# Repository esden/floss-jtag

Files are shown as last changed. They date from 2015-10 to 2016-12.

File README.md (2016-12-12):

Free Libre Open-Source/-Hardware JTAG/UART Adapter based on the FT2232H chip.

The hardware is licensed under Creative Commons Share Alike By Attribution 3.0 (CC-BY-SA 3.0)

Copyright 2009-2010 Piotr Esden-Tempski

# UART connector adapter side:

| Pin No. | Name  |
|---|---|
| 1 | +3.3V |
| 2 |  TXD  |
| 3 |  RXD  |
| 4 |  GND  |

The numbering of the connector is from left to right when looking from the edge
of the board at the pins of the header.

# Hardware design file notes:

All designs up until version 1.0 of Floss-JTAG were
designed in Cadsoft EAGLE. To view the files you will need to install EAGLE.
Most of the designs are 4-layer; this means that you will need a paid version
of the software to edit the inner layers of the board.

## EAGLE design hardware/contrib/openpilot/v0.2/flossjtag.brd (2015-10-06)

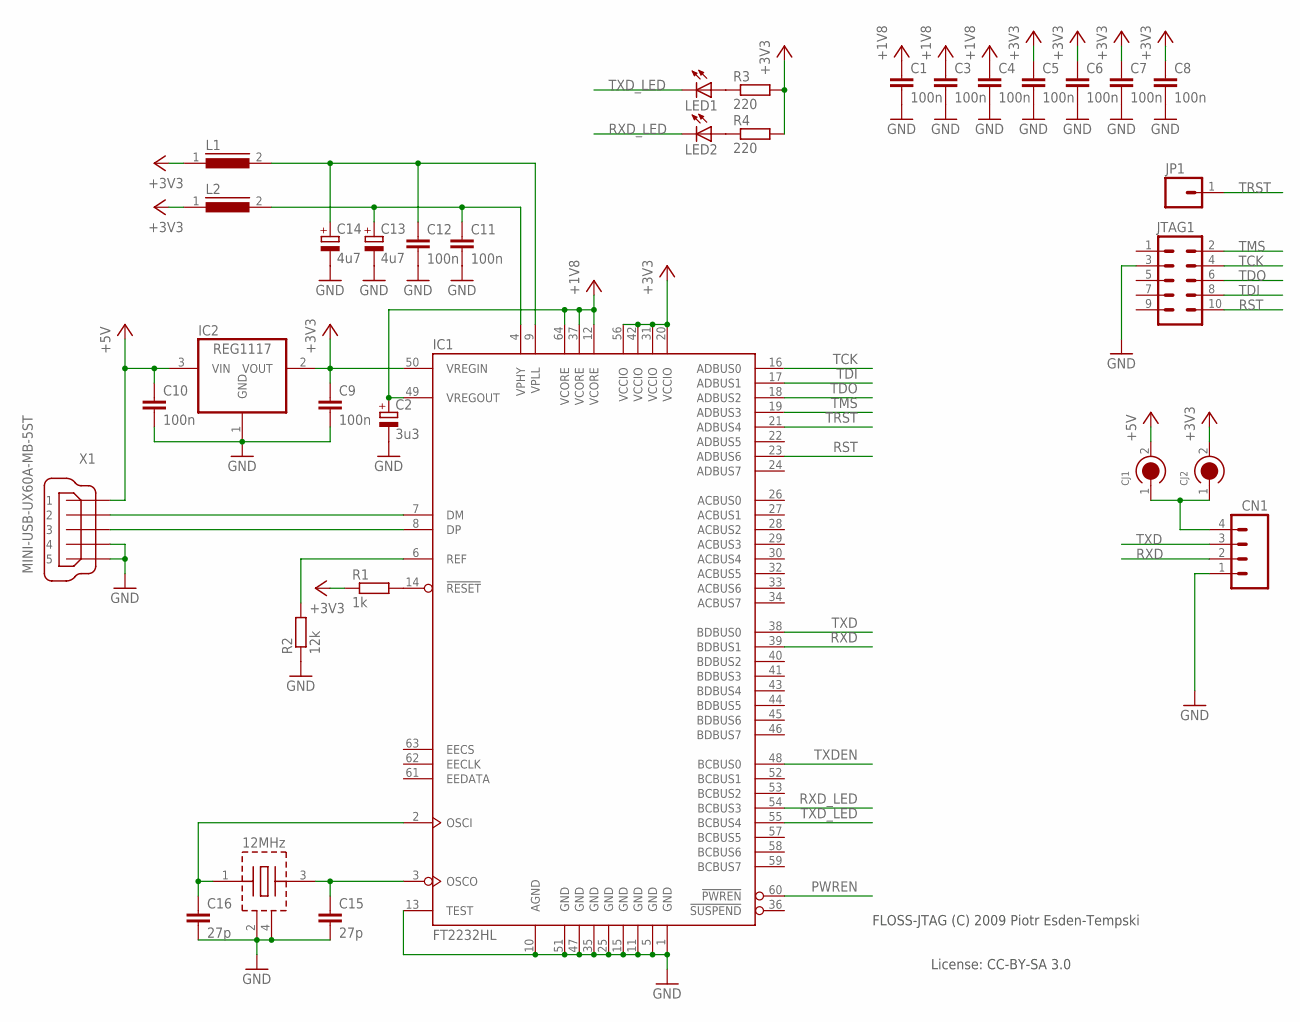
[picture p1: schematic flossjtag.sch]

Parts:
C1, C3, C4, C5, C6, C7, C8, C9, C10, C11, C12: 100n; C0603
C2: 3u3; A/3216-18R
C13, C14: 4u7; A/3216-18R
C15, C16: 27p; C0603
CJ1, CJ2: CIRC_JMP
CN1: SM04B-SRSS-TB
IC1: FT2232HL; LQFP64
IC2: REG1117; SOT223
JP1: PAD-0.06
JTAG1: JTAG-EDGE
L1, L2: I0603; R0603
LED1, LED2: LEDCHIP-LED0603; CHIP-LED0603
R1: 1k; R0603
R2: 12k; R0603
R3, R4: 220; R0603
X1: MINI-USB-UX60A-MB-5ST; UX60A-MB-5ST
X3: 12MHz; NX3225SA

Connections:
+3V3: C5.1, C6.1, C7.1, C8.1, C9.1, CJ2.2, IC1.20 (VCCIO), IC1.31 (VCCIO), IC1.42 (VCCIO), IC1.50 (VREGIN), IC1.56 (VCCIO), IC2.2 (VOUT), L1.1, L2.1, R1.1, R3.2, R4.2
+5V: C10.1, CJ1.2, IC2.3 (VIN), X1.1
GND: C1.2, C2.-, C3.2, C4.2, C5.2, C6.2, C7.2, C8.2, C9.2, C10.2, C11.2, C12.2, C13.-, C14.-, C15.2, C16.2, CN1.1, IC1.1 (GND), IC1.5 (GND), IC1.10 (AGND), IC1.11 (GND), IC1.13 (TEST), IC1.15 (GND), IC1.25 (GND), IC1.35 (GND), IC1.47 (GND), IC1.51 (GND), IC2.1 (GND), JTAG1.3, R2.1, X1.4, X1.5, X3.2 (GND), X3.4 (GND)
unnamed: IC1.14 (!RESET), R1.2
unnamed: IC1.6 (REF), R2.2
unnamed: IC1.7 (DM), X1.2
unnamed: IC1.8 (DP), X1.3
unnamed: CJ1.1, CJ2.1, CN1.4
unnamed: C16.1, IC1.2 (OSCI), X3.1 (XTAL)
unnamed: C12.1, C14.+, IC1.9 (VPLL), L1.2
unnamed: C11.1, C13.+, IC1.4 (VPHY), L2.2
unnamed: C15.1, IC1.3 (OSCO), X3.3 (XTAL)
unnamed: LED1.A, R3.1
unnamed: LED2.A, R4.1
PWREN: IC1.60 (!PWREN)
RST: IC1.23 (ADBUS6), JTAG1.10
RXD: CN1.2, IC1.39 (BDBUS1)
RXD_LED: IC1.54 (BCBUS3), LED2.C
TCK: IC1.16 (ADBUS0), JTAG1.4
TDI: IC1.17 (ADBUS1), JTAG1.8
TDO: IC1.18 (ADBUS2), JTAG1.6
TMS: IC1.19 (ADBUS3), JTAG1.2
TRST: IC1.21 (ADBUS4), JP1.1
TXD: CN1.3, IC1.38 (BDBUS0)
TXDEN: IC1.48 (BCBUS0)
TXD_LED: IC1.55 (BCBUS4), LED1.C
VCC: C1.1, C2.+, C3.1, C4.1, IC1.12 (VCORE), IC1.37 (VCORE), IC1.49 (VREGOUT), IC1.64 (VCORE)

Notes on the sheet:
FLOSS-JTAG (C) 2009 Piotr Esden-Tempski
License: CC-BY-SA 3.0

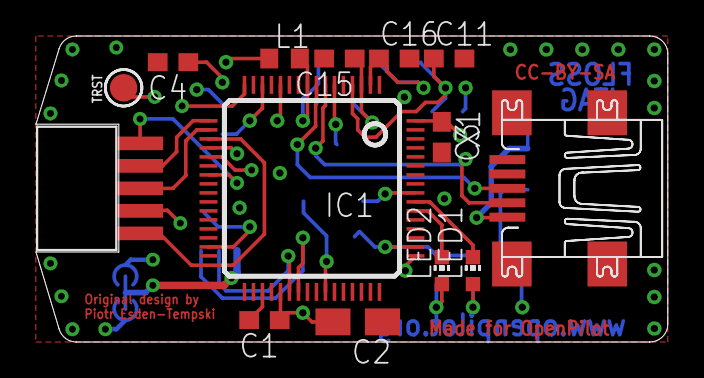
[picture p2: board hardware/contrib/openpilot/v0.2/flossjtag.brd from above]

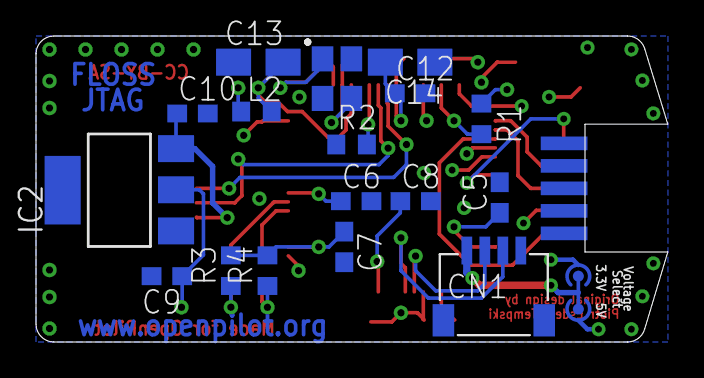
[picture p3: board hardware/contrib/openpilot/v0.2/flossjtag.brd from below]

Board: 4 copper layers, 35.1 x 17.0 mm, 33 parts (19 on the bottom side), 25 nets.

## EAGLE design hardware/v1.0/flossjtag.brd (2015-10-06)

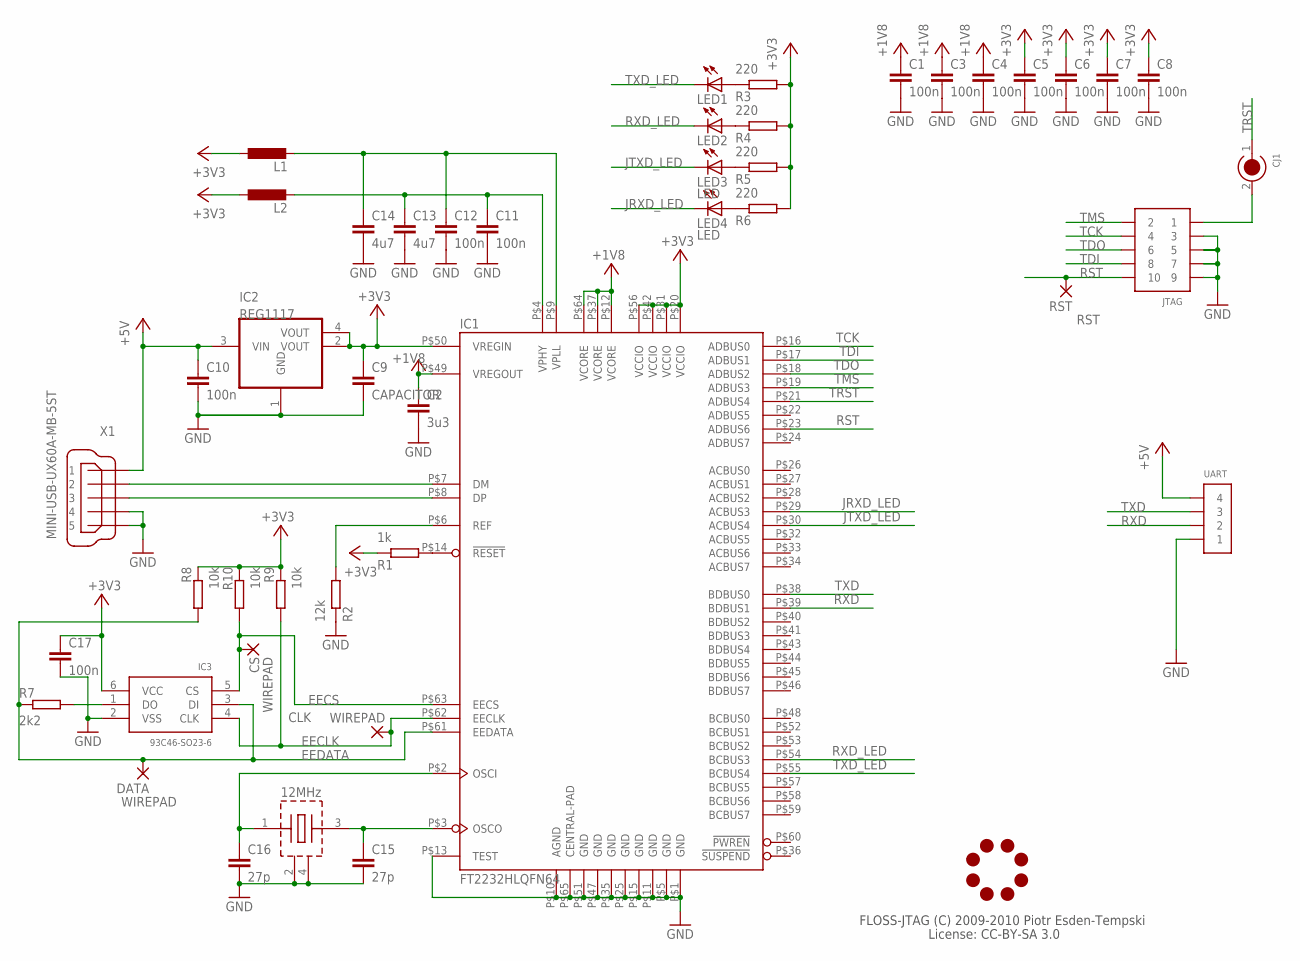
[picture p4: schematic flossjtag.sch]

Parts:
C1, C3, C4, C5, C6, C7, C8, C10, C11, C12, C17: 100n; 0603-CAP
C2: 3u3; 0603-CAP
C9: CAPACITOR; 0603-CAP
C13, C14: 4u7; 0603-CAP
C15, C16: 27p; 0603-CAP
CJ1: CIRC_JMP
CLK: WIREPAD; SMD1,27
CS: WIREPAD; SMD1,27
DATA: WIREPAD; SMD1,27
IC1: FT2232HLQFN64; QFN64
IC2: REG1117; SOT223
IC3: 93C46-SO23-6; SO23-6
JL1: JOBY_LOGO-6MIL; JOBY_LOGO_6MIL
JTAG: CONN_5-2-FTSH-V; FTSH-105-DV
L1, L2: INDUCTOR-0603; 0603-IND
LED1, LED2, LED3, LED4: LED; 0603-LED
R1: 1k; 0603-RES
R2: 12k; 0603-RES
R3, R4, R5, R6: 220; 0603-RES
R7: 2k2; 0603-RES
R8, R9, R10: 10k; 0603-RES
RST: RST; SMD1,27
UART: CONN_4-1; PB-53261-04
X1: MINI-USB-UX60A-MB-5ST; UX60A-MB-5ST
X3: 12MHz; NX3225SA

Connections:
+3V3: C5.P$1 (1), C6.P$1 (1), C7.P$1 (1), C8.P$1 (1), C9.P$1 (1), C17.P$1 (1), IC1.P$20 (VCCIO), IC1.P$31 (VCCIO), IC1.P$42 (VCCIO), IC1.P$50 (VREGIN), IC1.P$56 (VCCIO), IC2.2 (VOUT), IC2.4 (VOUT), IC3.6 (VCC), L1.P$1 (1), L2.P$1 (1), R1.P$1 (1), R3.P$2 (2), R4.P$2 (2), R5.P$2 (2), R6.P$2 (2), R8.P$1 (1), R9.P$1 (1), R10.P$1 (1)
+5V: C10.P$1 (1), IC2.3 (VIN), UART.4, X1.1
EECLK: CLK.1, IC1.P$62 (EECLK), IC3.4 (CLK), R9.P$2 (2)
EECS: CS.1, IC1.P$63 (EECS), IC3.5 (CS), R10.P$2 (2)
EEDATA: DATA.1, IC1.P$61 (EEDATA), IC3.3 (DI), R7.P$1 (1), R8.P$2 (2)
GND: C1.P$2 (2), C2.P$2 (2), C3.P$2 (2), C4.P$2 (2), C5.P$2 (2), C6.P$2 (2), C7.P$2 (2), C8.P$2 (2), C9.P$2 (2), C10.P$2 (2), C11.P$2 (2), C12.P$2 (2), C13.P$2 (2), C14.P$2 (2), C15.P$2 (2), C16.P$2 (2), C17.P$2 (2), IC1.P$1 (GND), IC1.P$5 (GND), IC1.P$10 (AGND), IC1.P$11 (GND), IC1.P$13 (TEST), IC1.P$15 (GND), IC1.P$25 (GND), IC1.P$35 (GND), IC1.P$47 (GND), IC1.P$51 (GND), IC1.P$65 (CENTRAL-PAD), IC2.1 (GND), IC3.2 (VSS), JTAG.3, JTAG.5, JTAG.7, JTAG.9, R2.P$1 (1), UART.1, X1.4, X1.5, X3.2 (GND), X3.4 (GND)
JRXD_LED: IC1.P$29 (ACBUS3), LED4.C
JTXD_LED: IC1.P$30 (ACBUS4), LED3.C
unnamed: IC1.P$14 (!RESET), R1.P$2 (2)
unnamed: IC1.P$6 (REF), R2.P$2 (2)
unnamed: IC1.P$7 (DM), X1.2
unnamed: IC1.P$8 (DP), X1.3
unnamed: C16.P$1 (1), IC1.P$2 (OSCI), X3.1 (XTAL)
unnamed: C12.P$1 (1), C14.P$1 (1), IC1.P$9 (VPLL), L1.P$2 (2)
unnamed: C11.P$1 (1), C13.P$1 (1), IC1.P$4 (VPHY), L2.P$2 (2)
unnamed: C15.P$1 (1), IC1.P$3 (OSCO), X3.3 (XTAL)
unnamed: LED1.A, R3.P$1 (1)
unnamed: LED2.A, R4.P$1 (1)
unnamed: LED3.A, R5.P$1 (1)
unnamed: LED4.A, R6.P$1 (1)
unnamed: IC3.1 (DO), R7.P$2 (2)
unnamed: CJ1.2, JTAG.1
RST: IC1.P$23 (ADBUS6), JTAG.10, RST.1
RXD: IC1.P$39 (BDBUS1), UART.2
RXD_LED: IC1.P$54 (BCBUS3), LED2.C
TCK: IC1.P$16 (ADBUS0), JTAG.4
TDI: IC1.P$17 (ADBUS1), JTAG.8
TDO: IC1.P$18 (ADBUS2), JTAG.6
TMS: IC1.P$19 (ADBUS3), JTAG.2
TRST: CJ1.1, IC1.P$21 (ADBUS4)
TXD: IC1.P$38 (BDBUS0), UART.3
TXD_LED: IC1.P$55 (BCBUS4), LED1.C
VCC: C1.P$1 (1), C2.P$1 (1), C3.P$1 (1), C4.P$1 (1), IC1.P$12 (VCORE), IC1.P$37 (VCORE), IC1.P$49 (VREGOUT), IC1.P$64 (VCORE)

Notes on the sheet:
FLOSS-JTAG (C) 2009-2010 Piotr Esden-Tempski
License: CC-BY-SA 3.0

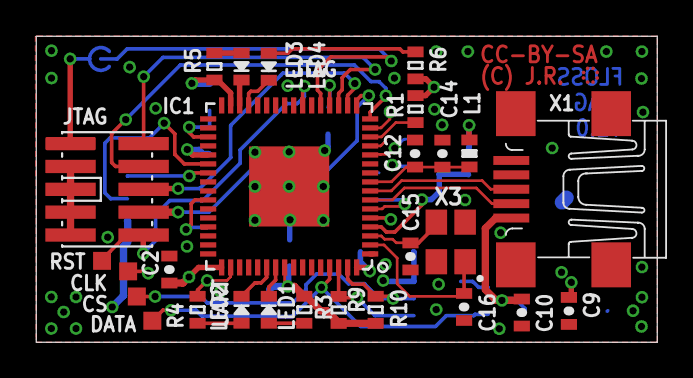
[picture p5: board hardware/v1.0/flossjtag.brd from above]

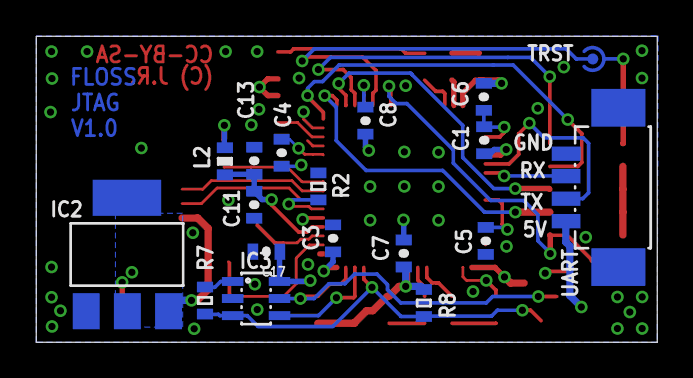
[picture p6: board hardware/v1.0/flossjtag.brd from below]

Board: 4 copper layers, 34.5 x 17.0 mm, 47 parts (18 on the bottom side), 33 nets.

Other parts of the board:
DRILEGEND: DRILEGEND

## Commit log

2009-10-15 Initial commit of FLOSS-JTAG.
    [flossjtag.brd, flossjtag.sch]
2009-10-15 Fixed RST line, to be compatible with DLP-USB1232H, this one is already supported by OpenOCD.
    [flossjtag.brd, flossjtag.sch]
2009-10-15 Connected one last airwire that I overlooked...
    [flossjtag.brd]
2009-10-15 Moved some vias so that teardrops are possible without breaking DRC.
    [flossjtag.brd]
2009-10-15 Created a teardrop version of the board.
    [flossjtag-teardrops.brd]
2009-10-15 Added molex to 20pin adapter board.
    [20pin-adapter.brd, 20pin-adapter.sch]
2009-10-15 Added 20pin adapter teardrops version.
    [20pin-adapter-teardrops.brd]
2009-10-15 Added makefiles for generating gerber files and panelization.
    [layout.cfg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]
2009-10-15 Changed all vias to be closed. (Covered with soldermask)
    [20pin-adapter-teardrops.brd, 20pin-adapter.brd, flossjtag-teardrops.brd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]
2009-10-16 Updated CRYSTAL to have a value. Added used libraries.
    [flossjtag-teardrops.brd, flossjtag.brd, flossjtag.sch]
2009-10-17 Made texts bigger as requested by pcbcard, added text and some vias to the adapter board.
    [20pin-adapter-teardrops.brd, 20pin-adapter.brd, flossjtag-teardrops.brd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]
2009-10-19 Changed distance between the boards on the panel from 3mm to 2mm. (PCBCard tabrouting is made with 2mm router)
    [layout.cfg]
2009-10-19 Increased text size again. Now it should be big enough!
    [20pin-adapter-teardrops.brd, 20pin-adapter.brd, flossjtag-teardrops.brd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]
2009-10-19 Exchanged old boring solder jumpers with new fancy ones. ^^
    [flossjtag-teardrops.brd, flossjtag.brd, flossjtag.sch]
2009-11-12 Connected pin 5 of the usb connector to GND as it should be.
    [flossjtag.brd, flossjtag.sch]
2009-11-16 Fixed footprint of the ft2232 chip.
    [flossjtag.brd, flossjtag.sch]
2009-12-03 Moved the v0.1 directory to v0.2. v0.1 was broken so should not be visible anymore.
    [flossjtag-teardrops.brd, flossjtag.brd, flossjtag.sch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]
2009-12-03 Updated the version number in the board file to v0.2.
    [flossjtag.brd]
2009-12-03 Updated the teardrop version of flossjtag to the current version.
    [flossjtag-teardrops.brd]
2010-01-27 Added 93C46 eeprom with sot32-6 footprint to lib.
2010-01-27 Started v0.3 with pretty-eagle-lib parts and eeprom.
    [flossjtag.brd, flossjtag.sch, layout.cfg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]
2010-01-27 Added OpenPiolt (http://www.openpilot.org) derivate.
    Thanks to Angus Peart for using and adapting
    Floss-JTAG for OpenPilot.
    [flossjtag.brd, flossjtag.sch]
2010-09-08 Replaced the non standard jtag connector with standard cortex.
    [flossjtag.brd, flossjtag.sch]
2010-09-15 Updated silkscreen on v0.2 for easier assembly.
    [flossjtag.brd]
2010-09-15 Advances on v0.3 routing.
    [flossjtag.brd, flossjtag.sch]
2010-10-18 Finished version v0.3 of flossjtag.
    [flossjtag.brd, flossjtag.sch]
2010-10-20 Finished routing of fj v1.0. Some DRC errors need to be fixed though.
    [flossjtag.brd, flossjtag.sch]
2010-10-20 Fixed or approved all DRC errors and warnings.
    [flossjtag.brd]
2010-10-20 Created teardropped version of fj 1.0.
    [flossjtag-teardrops.brd, flossjtag.brd]
2010-10-20 Added panel generation to fj 1.0
    [layout.cfg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]
2010-10-23 Increased size of vias to 0.4mm.
    [flossjtag.brd]
2010-10-23 Added some more GND vias. Fixed some remaining DRC Errors.
    [flossjtag.brd]
2010-10-26 Added eeprom bypass capacitor.
    [flossjtag.brd, flossjtag.sch]
2010-10-26 Updated teardrop version of FJ V1.0
    [flossjtag-teardrops.brd, flossjtag.brd]
2010-10-26 Added FJ V1.0 panel rails.
    [panel_rail.brd, panel_rail.sch]
2015-10-06 Updated all files to the newest version of Cadsoft Eagle.
    [20pin-adapter-teardrops.brd, 20pin-adapter.brd, 20pin-adapter.sch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]
2015-10-06 Improved the legend on the serial connector a bit.

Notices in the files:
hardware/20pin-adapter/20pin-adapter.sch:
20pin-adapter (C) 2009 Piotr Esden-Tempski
